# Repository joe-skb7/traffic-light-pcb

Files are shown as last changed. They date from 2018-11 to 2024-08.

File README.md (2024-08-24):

# "Traffic Light" system: hardware design files

Hardware files for traffic light model and interfacing board.

Corresponding software for controlling the interface board can be found at [1].

## Photo

Interfacing board, top view:

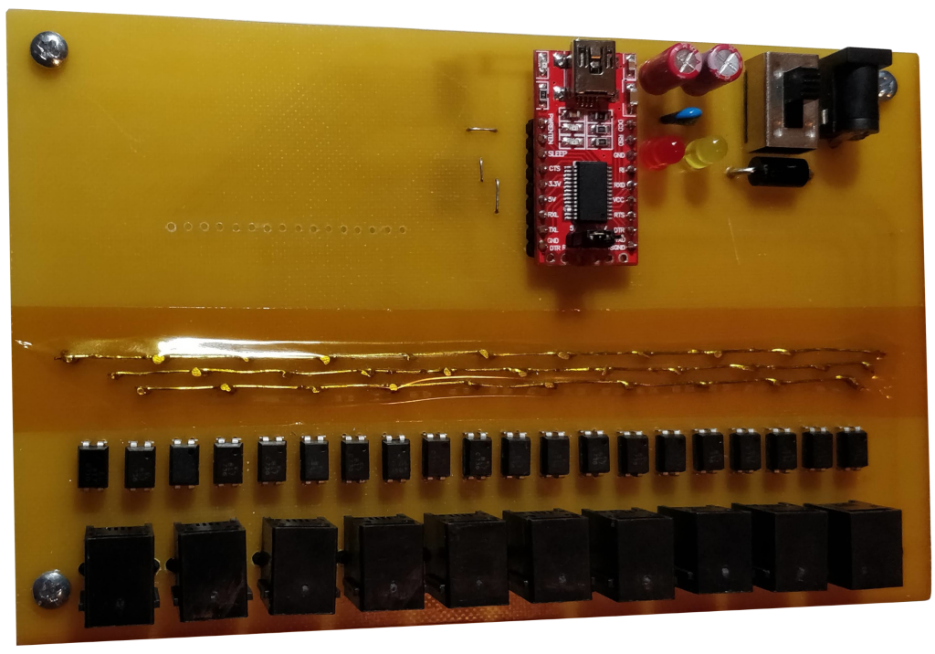
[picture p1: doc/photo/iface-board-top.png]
Interfacing Board, Top View


Interfacing board, bottom view:

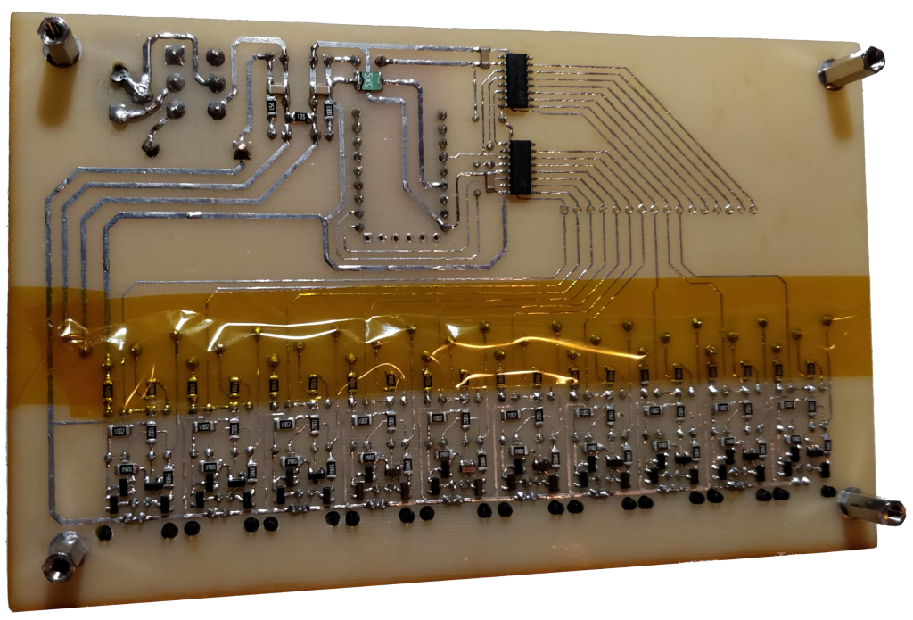
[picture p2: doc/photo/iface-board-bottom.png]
Interfacing Board, Bottom View


Traffic light board:

Traffic Light Board

## Overview

This repository consists of two KiCad projects:

1. Traffic light board (`light/*`):
   - it has 5 red and 5 green LEDs on it
2. Interfacing board (`iface/*`):
   - connect it to your PC (via USB cable) from one side
   - connect it to up to 10 traffic light boards (via phone cable) from other
     side

Kicad v5.0.1 was used.

You can find exported schematics in PDF format in `doc/output/` directory.

Once connected, use libtrl [1] to control traffic light boards via interface
board.

## Authors

**Sam Protsenko**

## License

This project is licensed under the GPLv3.

## References

[1] https://github.com/joe-skb7/libtrl

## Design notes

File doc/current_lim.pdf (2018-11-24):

### Simple Current Limit Circuit:

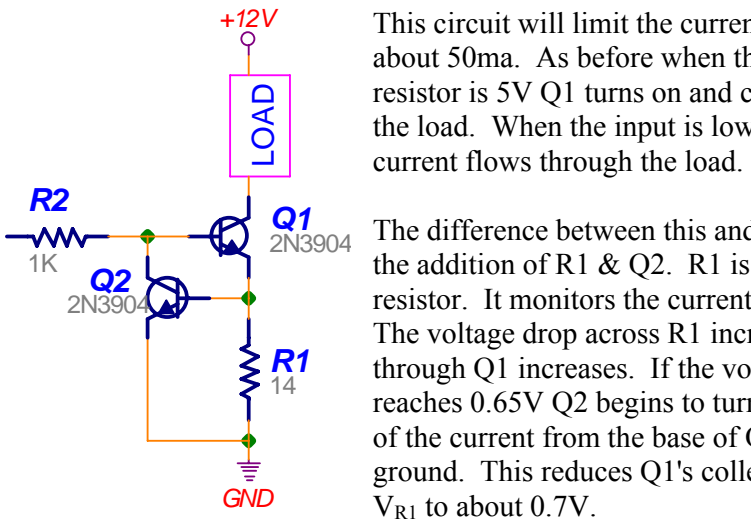
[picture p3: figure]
current flows through the load.; GND; 14LOAD; R1 to about 0.7V.

This circuit will limit the current through the load to about 50ma. As before when the input to the base resistor is 5V Q1 turns on and current flows through the load. When the input is low Q1 is off and no

GND

5V
The difference between this and the previous circuit is the addition of R1 & Q2. R1 is used as a current s resistor. It monitors the current flowing through Q1. The voltage drop across R1 increases as the curren through Q1 increases. If the voltage at the top of R1 reaches 0.65V Q2 begins to turn on. Q2 diverts some of the current from the base of Q1 and sends it to ground. This reduces Q1's collector current kee

ense

t

ping

The above circuit will act like a normal switch as long as the load doesn't try and draw too much current. If the load tries to draw too much current (50mA in this case) Q2 will divert some of the current away from Q1 and Q1 will increase the collector emitter voltage drop until the current is stable at about 50mA.

Calculations:

Let's say that Q2 turns on at 0.7V (it varies a little but this is close enough). We want to limit the current through the load to 50mA. The voltage drop across R1 should be 0.7V@50mA.
R1 = V/I = 0.7V/0.05A = 14Ω. Q1's base resistor is calculated the same as before but now you have to add in the extra 0.7V drop across the resistor. Since the worst case gain is 30 the base current should be: Ib = IC/30 = 50mA/30 = 1.7mA. We'll use 3mA so we have a safety margin.
R2 = (V – Vbe – VR1)/Ib = (5V – 0.7V – 0.7V)/3mA = 1.2KΩ. We'll use a 1KΩ (close enough).

Power dissipation:

Make sure you're transistor can dissipate the needed power in the worst case situation. If I short out the load with a wire (0Ω) almost the entire supply voltage (11.3V) will be dropped across the collector emitter junction of Q1 at 50mA. P = VI = 11.3V * 0.05A = 0.565W (quite a bit for the 2N3904).

Note: One reason to have a current limit is to protect the power supply incase the output gets shorted to ground. Without a current limit circuit a shorted power supply would most likely blow of fuse or melt a winding on the transformer (killing the supply). Always adjust the current limit on the bench power supply to only provide slightly more current than you think you need. This should keep you from destroying IC's & transistors when wired incorrectly.

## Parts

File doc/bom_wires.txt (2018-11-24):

1. Cable: Phone cable (4 wires, flat, copper, multicore/flexible).
   Qty: 100 meters (10 traffic lights, 10 meters per 1 traffic light).
   Possible option: [1].

2. Plugs: RJ9 (4P4C), for cable.
   Qty: 20 pcs (we need 10pcs, but let's buy 10 extra just in case).
   Possible option: [2].

3. Jacks: RJ9 (4P4C), for mounting on PCB, angled.
   Qty: 10 pcs.
   Possible option: [3].

4. Crimping tool for RJ9 (4P4C).
   Possible option: Hanlong HT-2094C [4].

References
----------

[1] https://e-server.com.ua/kabel-vitaya-para/telefonnyj-kabel/telefonnyj-kabel-4-zhily-ploskij-mednyj-chernyj-detail

[2] https://www.rcscomponents.kiev.ua/product/rj9-vilka-4p4c-kls12-rj11-4p4c-01_72297.html

[3] https://www.rcscomponents.kiev.ua/product/gnezdo-4p4c-kls12-123-4p4s-w-1-01-2-kls_72300.html

[4] https://e-server.com.ua/instrumenty-i-testery/instrumenty/instrument-dlya-obzhimaniya-konnektorov-rj-11-4p4c-4p2c-hanlong-detail

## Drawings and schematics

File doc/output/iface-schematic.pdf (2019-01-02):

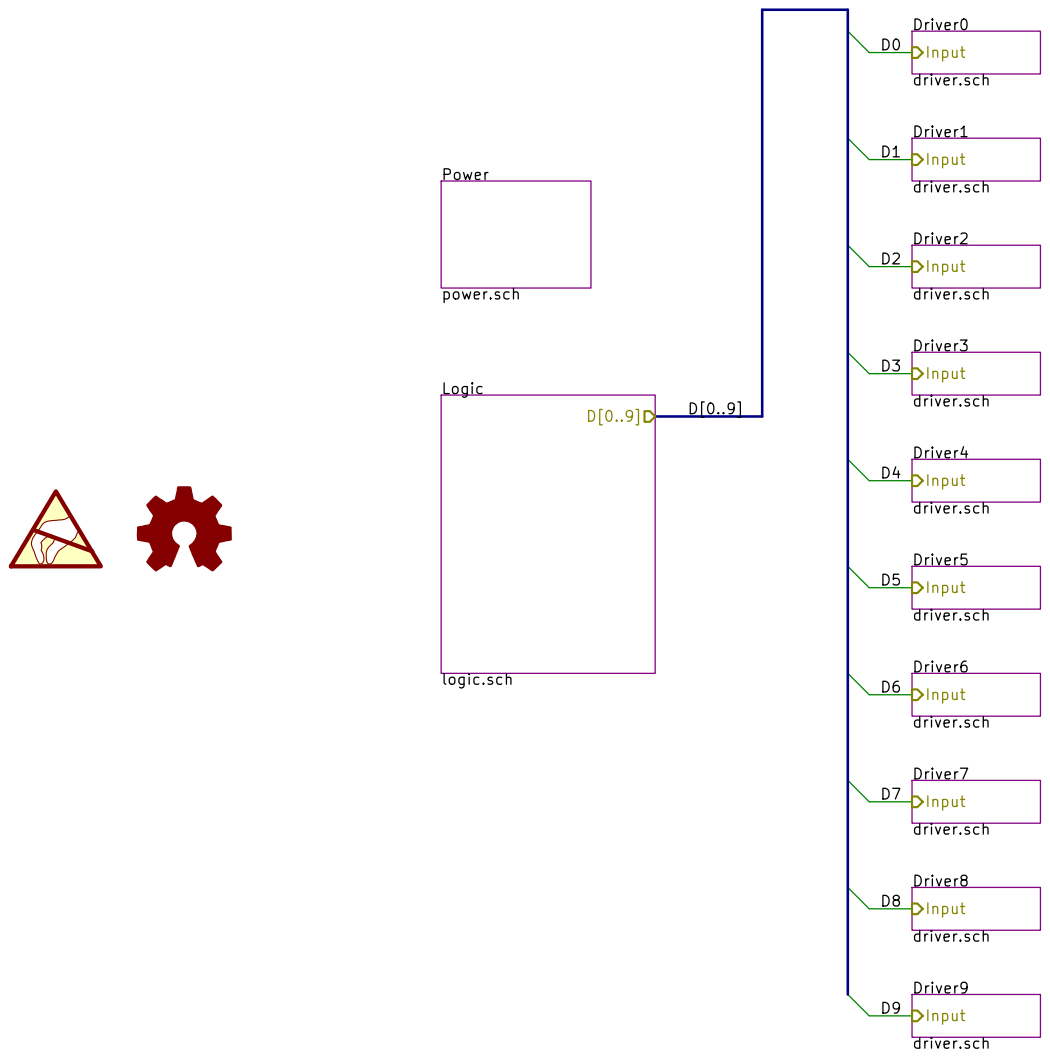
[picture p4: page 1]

Author: Sam Protsenko <semen.protsenko@globallogic.com>
File: iface.sch Sheet: / GlobalLogic

Id: 1/13 Title: Traffic Light Interface Board

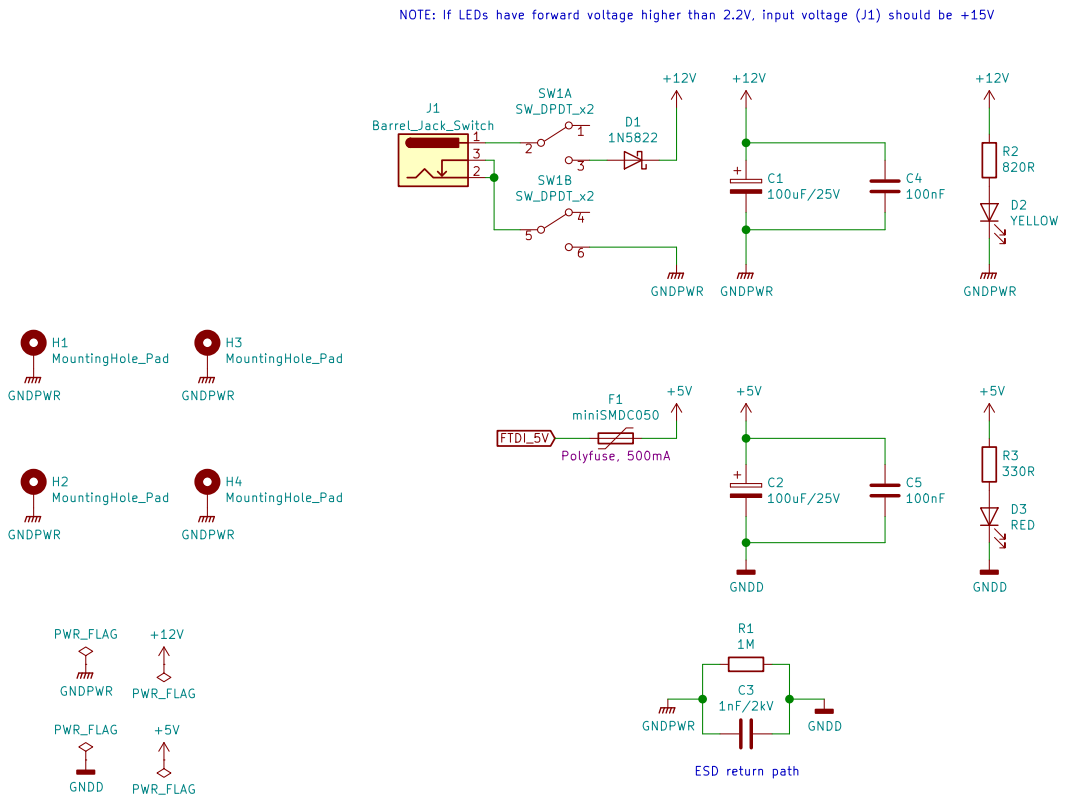
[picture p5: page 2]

SW_DPDT_x2 NOTE: If LEDs have forward voltage higher than 2.2V, input voltage (J1) should be +15V

Author: Sam Protsenko <semen.protsenko@globallogic.com>
File: power.sch Sheet: /Power/ GlobalLogic

Id: 2/13 Title: Power scheme

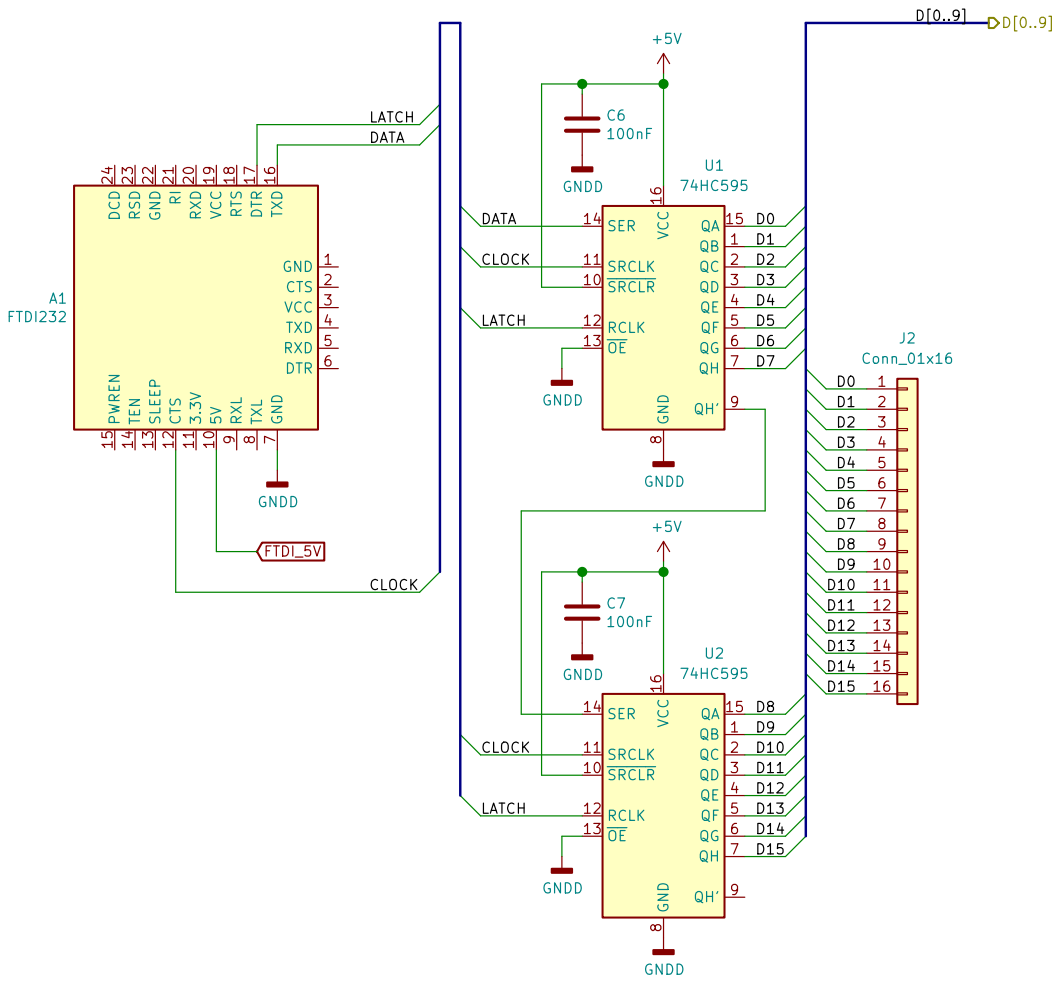
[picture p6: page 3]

Author: Sam Protsenko <semen.protsenko@globallogic.com>
GlobalLogic
Sheet: /Logic/
File: logic.sch
Id: 3/13 Title: Logic scheme

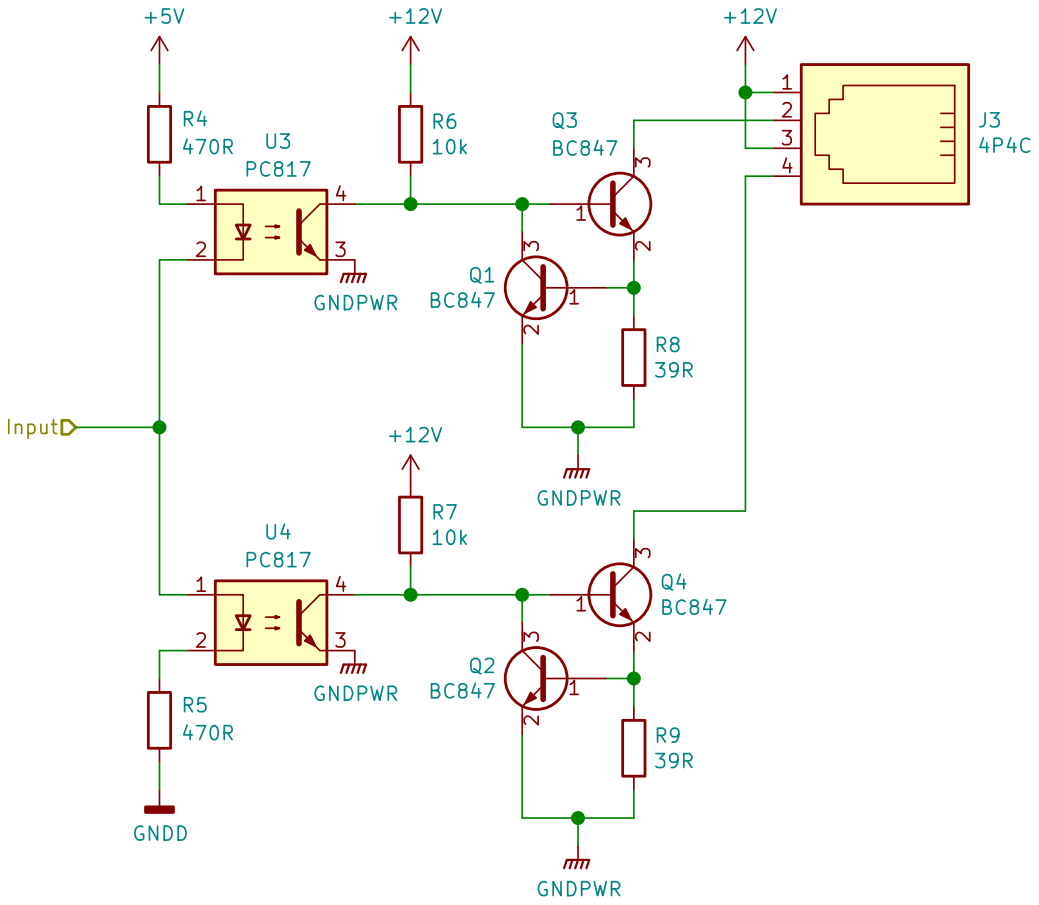
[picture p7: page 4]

Author: Sam Protsenko <semen.protsenko@globallogic.com>
Id: 4/13 Title: LED Driver File: driver.sch Sheet: /Driver0/ GlobalLogic

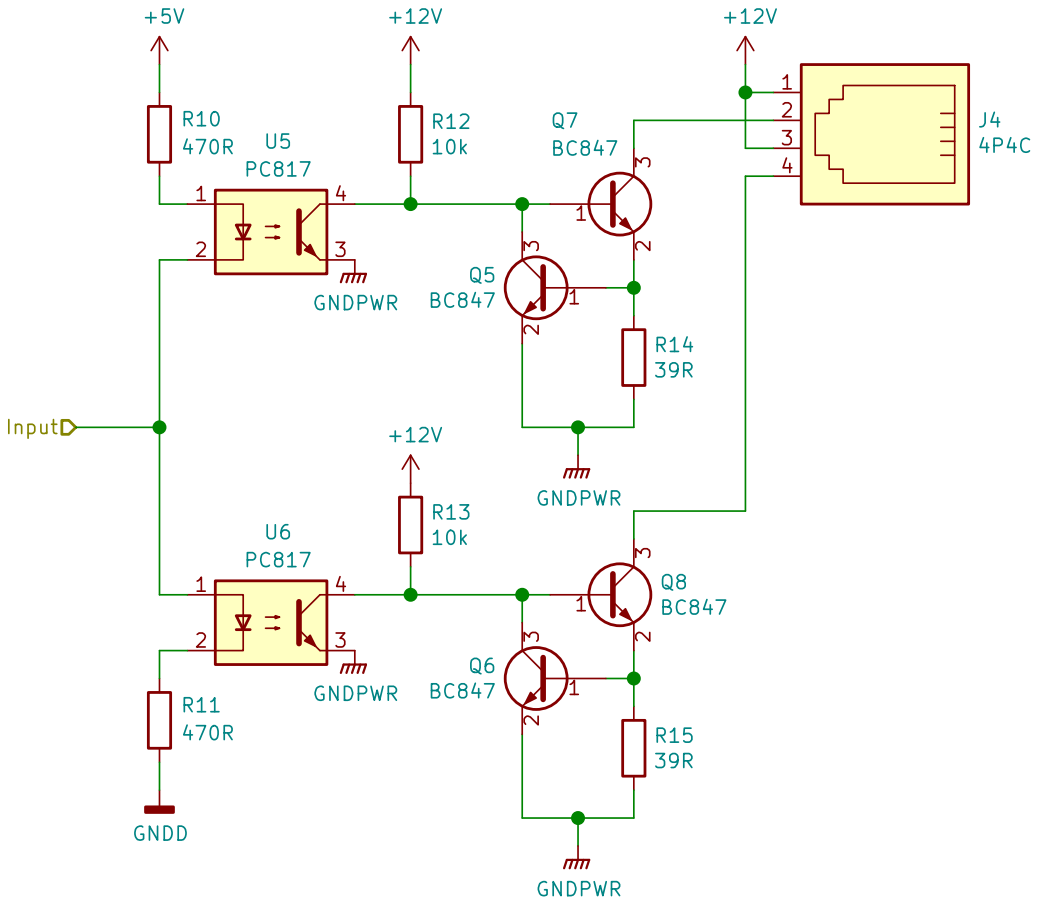
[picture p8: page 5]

Author: Sam Protsenko <semen.protsenko@globallogic.com>
Id: 5/13 Title: LED Driver File: driver.sch Sheet: /Driver1/ GlobalLogic

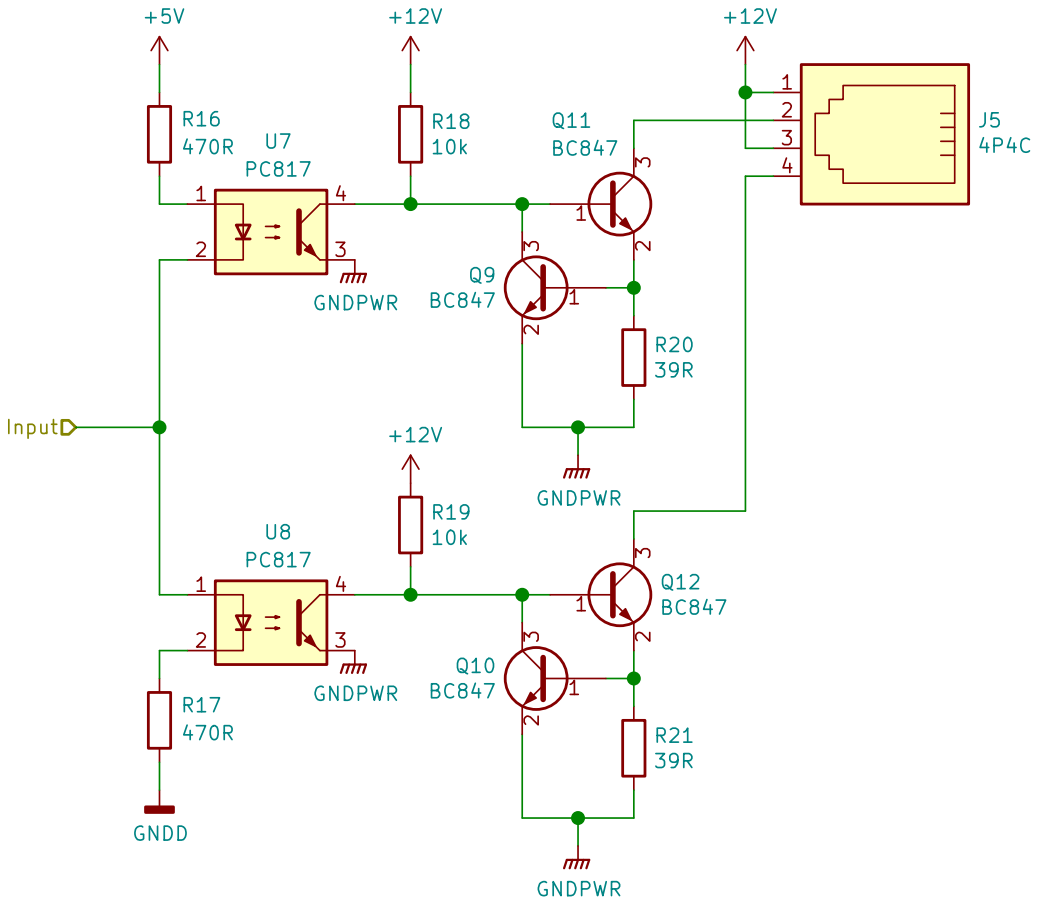
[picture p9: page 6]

Author: Sam Protsenko <semen.protsenko@globallogic.com>
Id: 6/13 Title: LED Driver File: driver.sch Sheet: /Driver2/ GlobalLogic

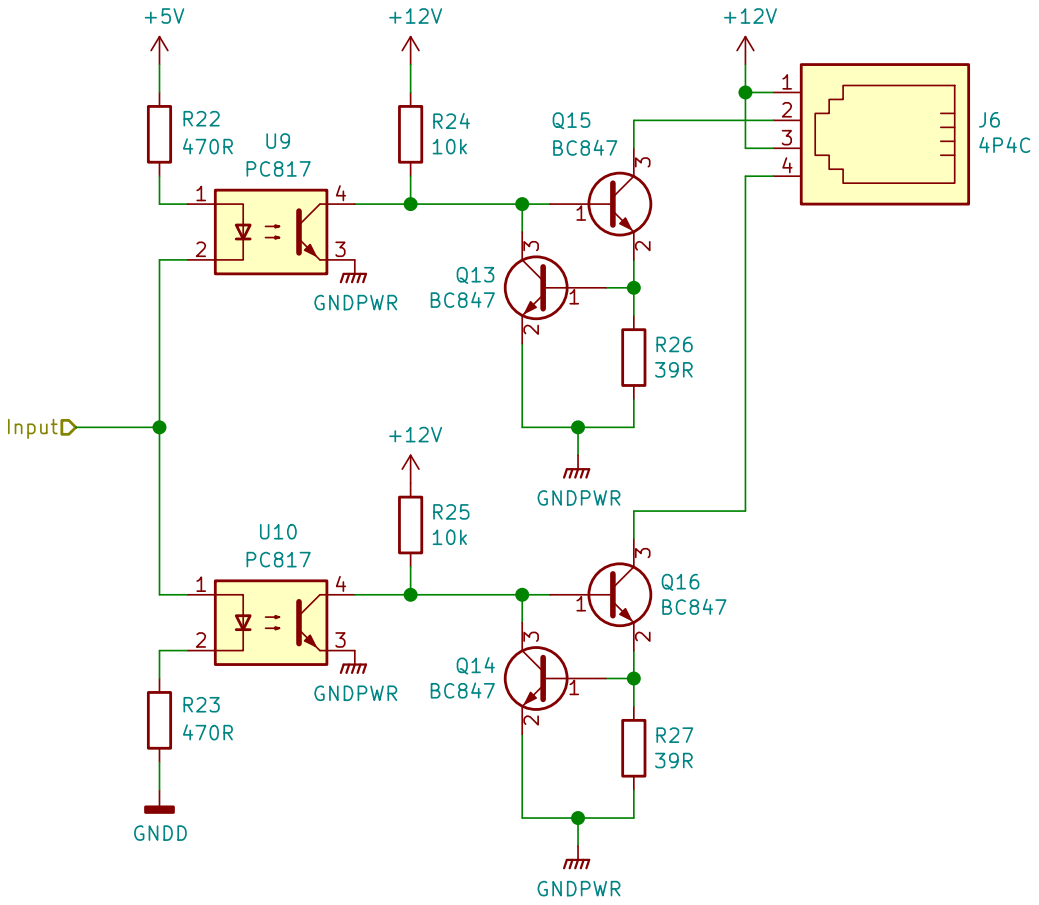
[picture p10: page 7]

Author: Sam Protsenko <semen.protsenko@globallogic.com>
Id: 7/13 Title: LED Driver File: driver.sch Sheet: /Driver3/ GlobalLogic

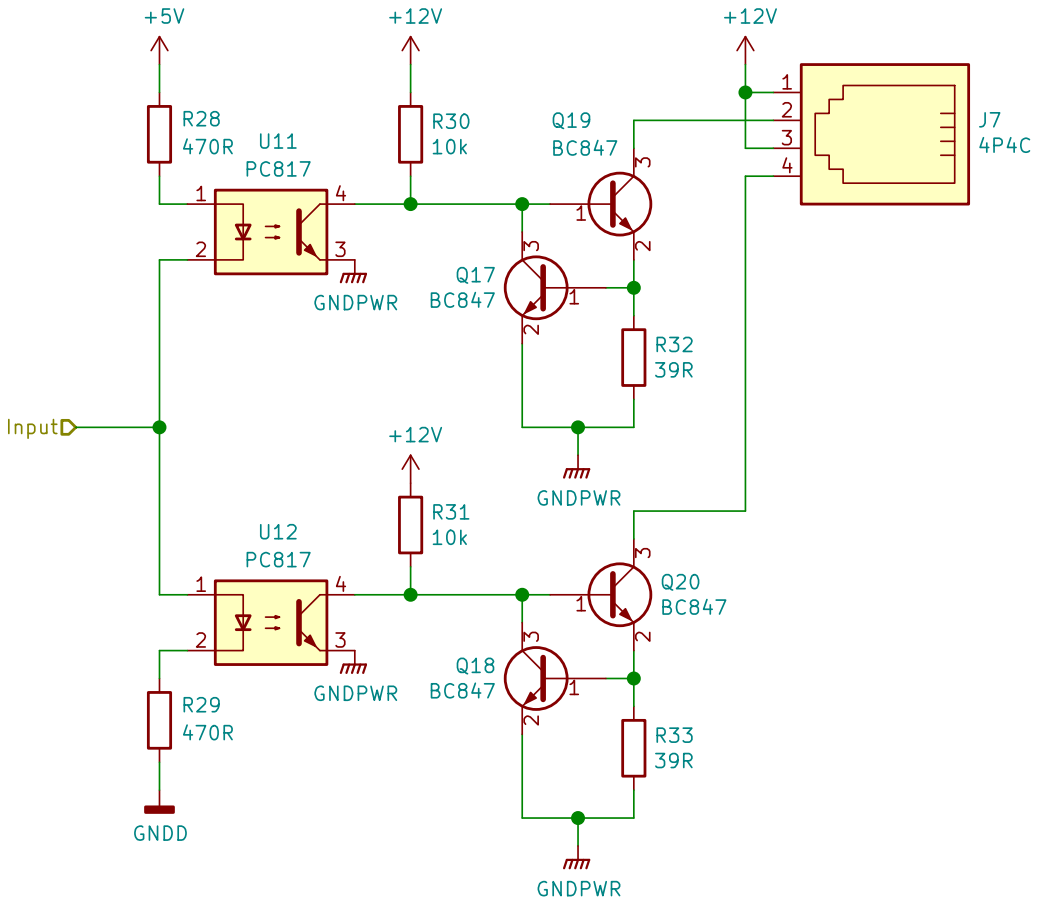
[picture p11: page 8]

Author: Sam Protsenko <semen.protsenko@globallogic.com>
Id: 8/13 Title: LED Driver File: driver.sch Sheet: /Driver4/ GlobalLogic

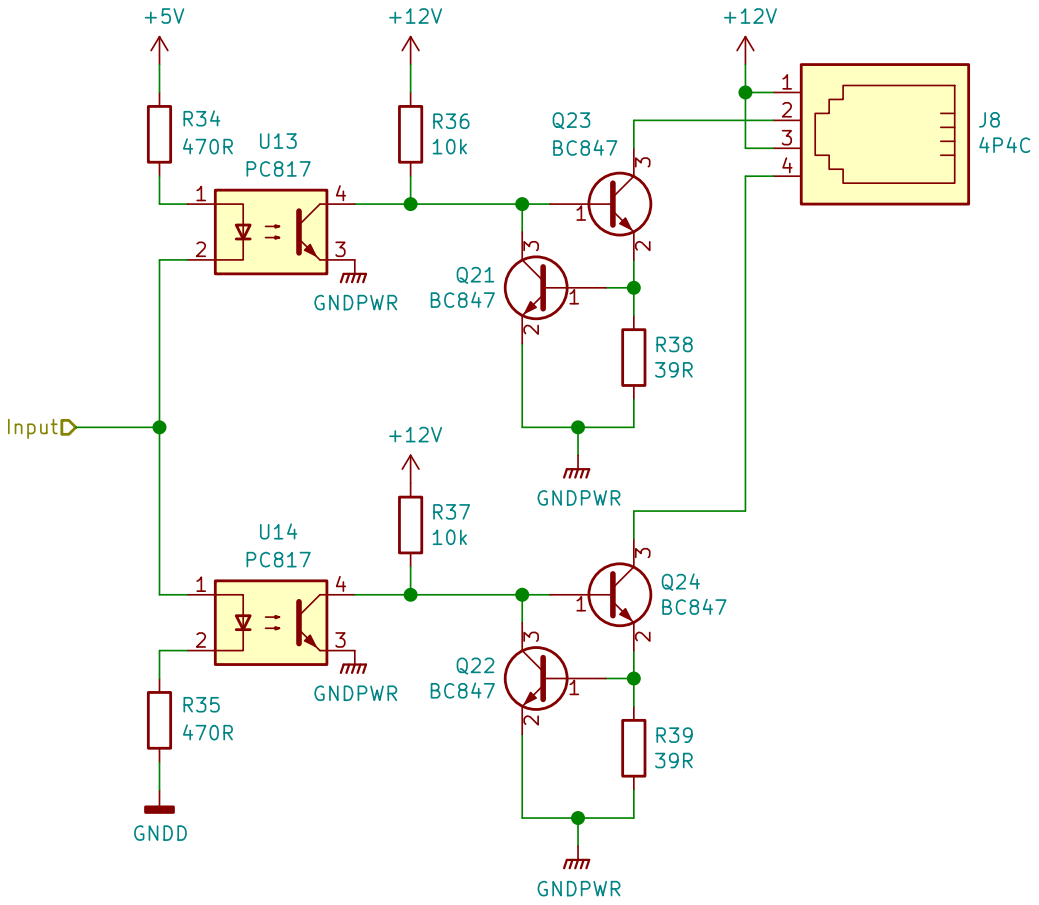
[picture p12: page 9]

Author: Sam Protsenko <semen.protsenko@globallogic.com>
Id: 9/13 Title: LED Driver File: driver.sch Sheet: /Driver5/ GlobalLogic

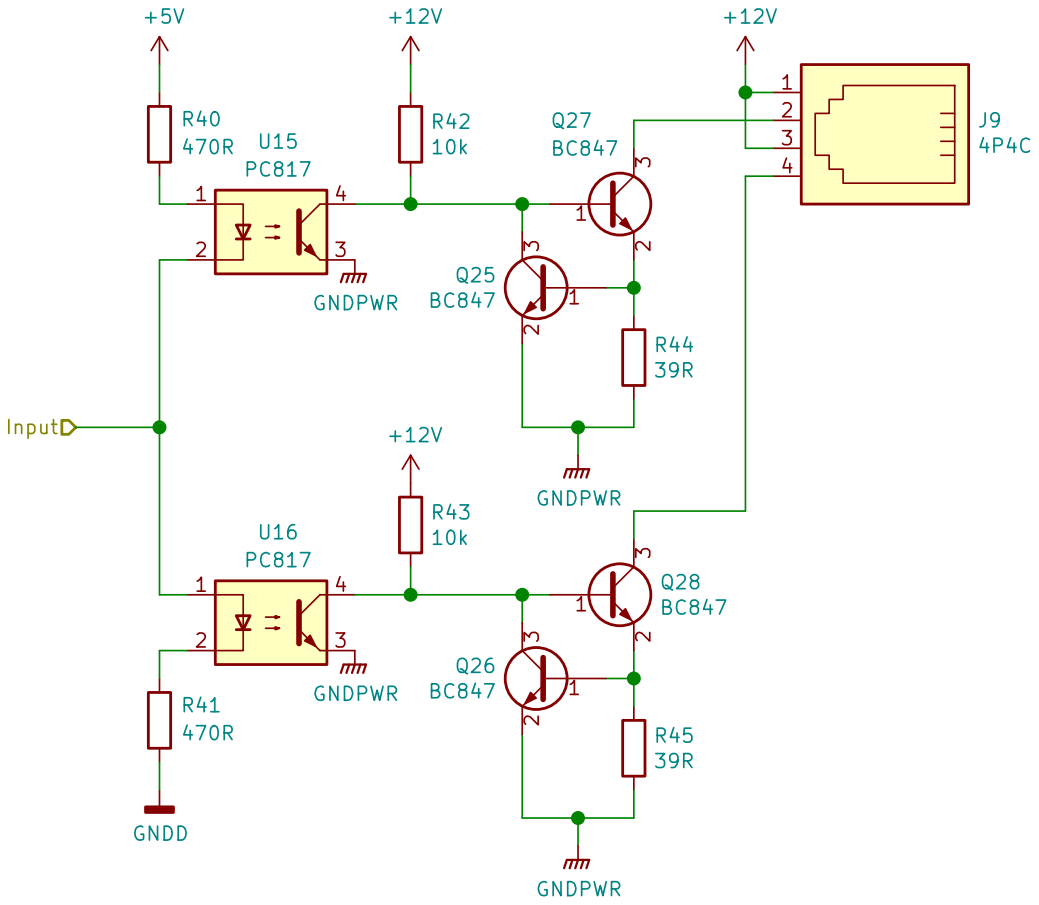
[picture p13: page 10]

Author: Sam Protsenko <semen.protsenko@globallogic.com>
Id: 10/13 Title: LED Driver File: driver.sch Sheet: /Driver6/ GlobalLogic

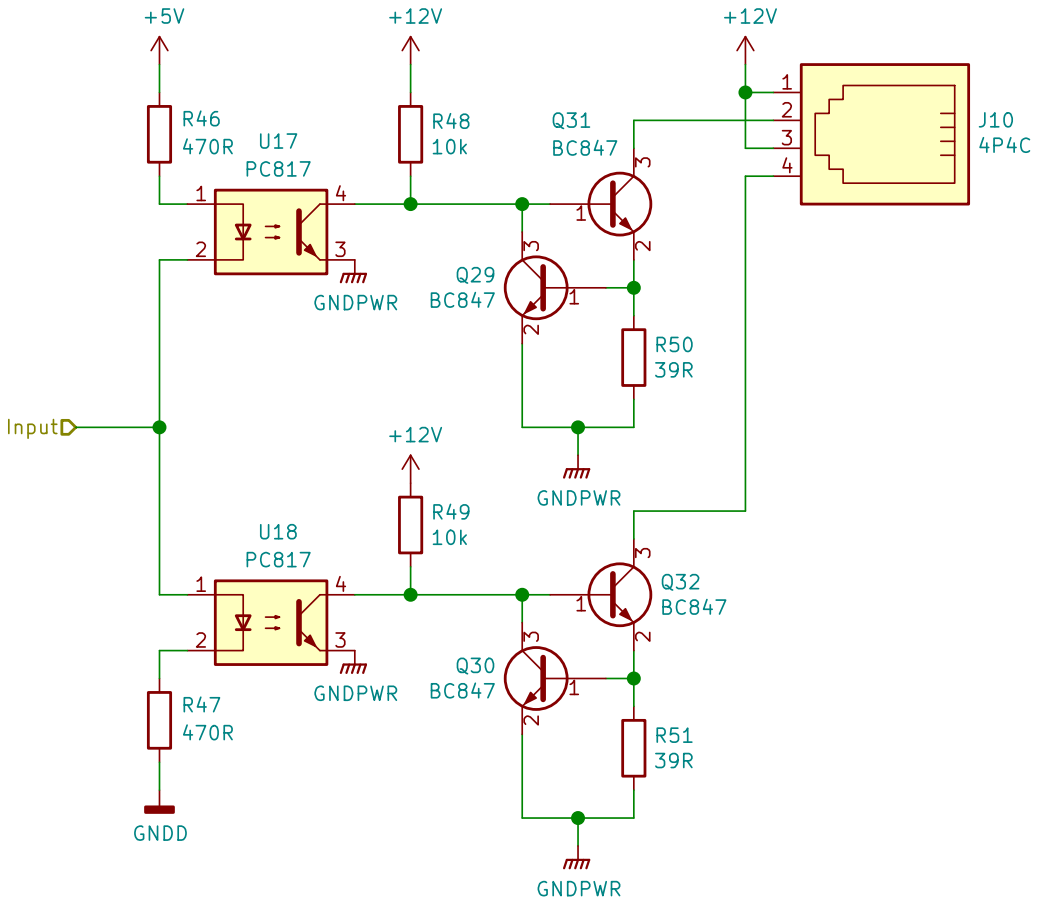
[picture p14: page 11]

Author: Sam Protsenko <semen.protsenko@globallogic.com>
Id: 11/13 Title: LED Driver File: driver.sch Sheet: /Driver7/ GlobalLogic

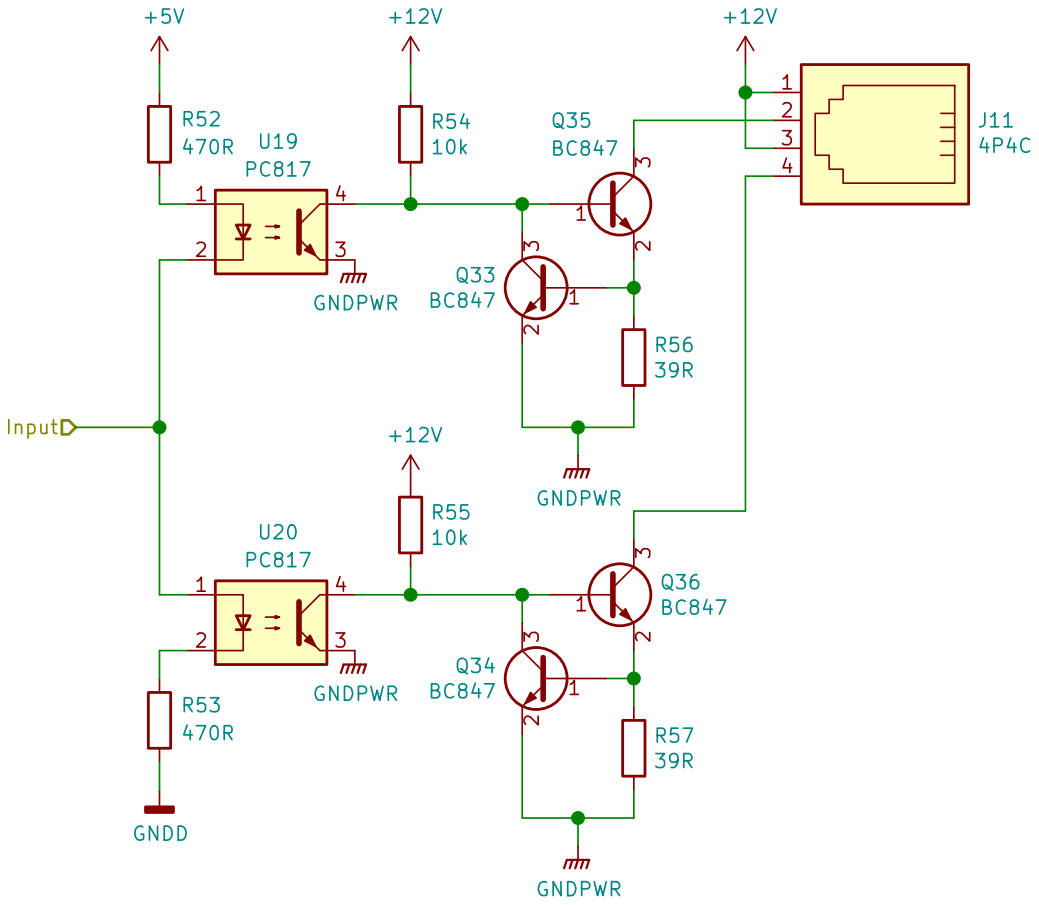
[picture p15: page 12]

Author: Sam Protsenko <semen.protsenko@globallogic.com>
Id: 12/13 Title: LED Driver File: driver.sch Sheet: /Driver8/ GlobalLogic


Author: Sam Protsenko <semen.protsenko@globallogic.com>
Id: 13/13 Title: LED Driver File: driver.sch Sheet: /Driver9/ GlobalLogic

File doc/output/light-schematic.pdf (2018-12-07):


Author: Sam Protsenko <semen.protsenko@globallogic.com>
File: light.sch Sheet: / GlobalLogic

Id: 1/1 Title: Traffic Light

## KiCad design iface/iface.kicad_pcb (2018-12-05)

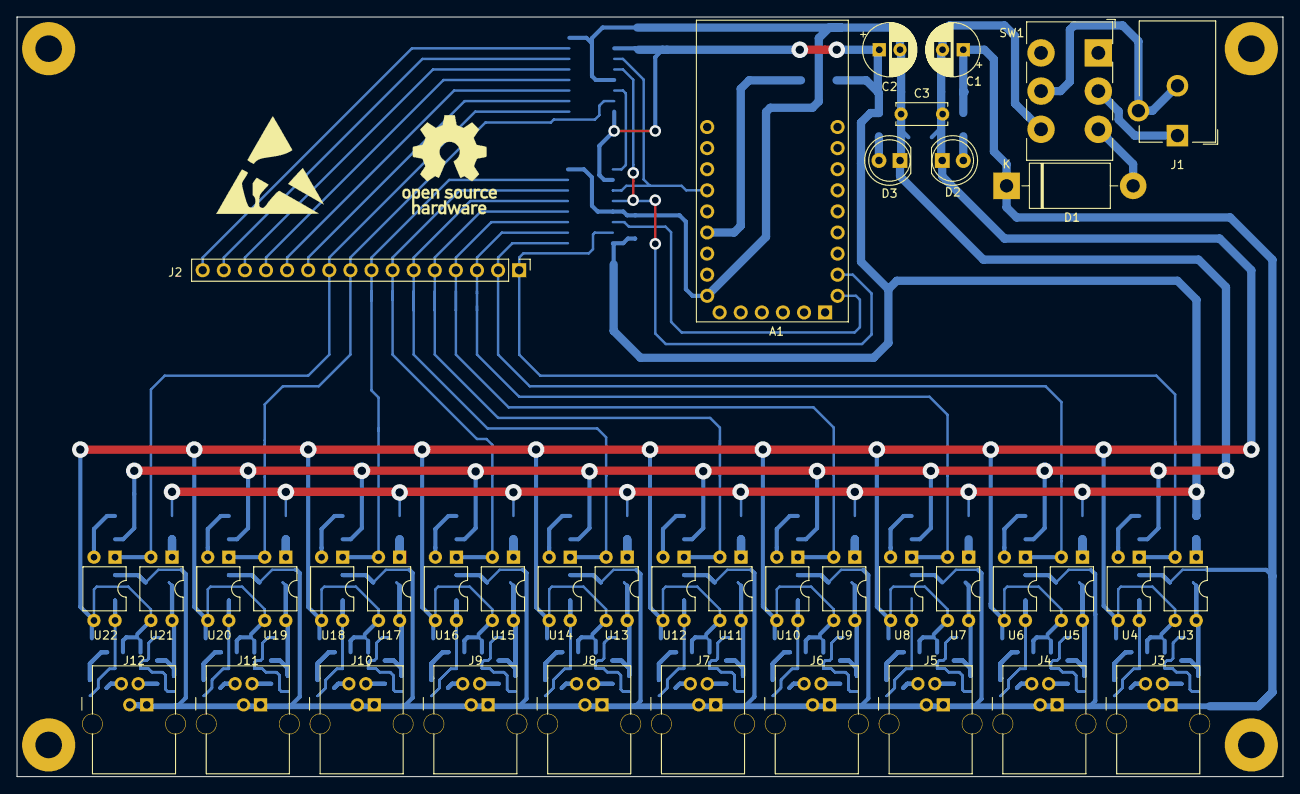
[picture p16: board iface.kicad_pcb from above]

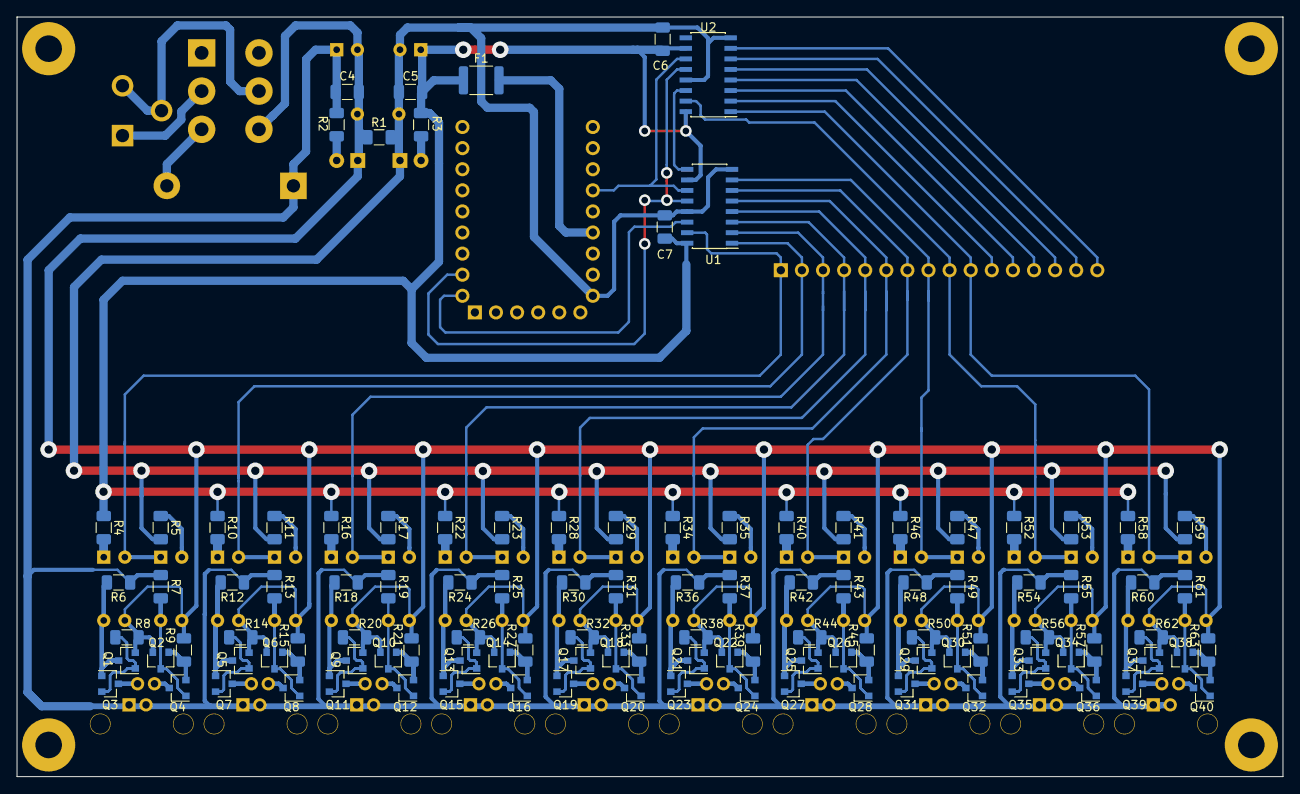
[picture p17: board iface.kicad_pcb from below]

Board: 2 copper layers, 152.4 x 91.4 mm, 156 parts (110 on the bottom side), 110 nets.

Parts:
A1: FTDI232
C1, C2: 100uF/25V; CP_Radial_D6.3mm_P2.50mm
C3: 1nF/2kV; C_Disc_D6.0mm_W2.5mm_P5.00mm
C4, C5, C6, C7: 100nF; C_1206_3216Metric
D1: 1N5822; D_DO-201AD_P15.24mm_Horizontal
D2: YELLOW; LED_D5.0mm
D3: RED; LED_D5.0mm
F1: Polyfuse; Fuse_1812_4532Metric
H1, H2, H3, H4: MountingHole_Pad; MountingHole_3.2mm_M3_Pad
J1: Barrel_Jack_Switch; BarrelJack_CUI_PJ-102AH_Horizontal
J2: Conn_01x16; PinHeader_1x16_P2.54mm_Vertical
J3, J4, J5, J6, J7, J8, J9, J10, J11, J12: 4P4C; RJ9_KLS_12-123-4P
Q1, Q2, Q3, Q4, Q5, Q6, Q7, Q8, Q9, Q10, Q11, Q12, Q13, Q14, Q15, Q16, Q17, Q18, Q19, Q20, Q21, Q22, Q23, Q24, Q25, Q26, Q27, Q28, Q29, Q30, Q31, Q32, Q33, Q34, Q35, Q36, Q37, Q38, Q39, Q40: BC847; SOT-23
R1: 1M; R_1206_3216Metric
R2: 820R; R_1206_3216Metric
R3: 330R; R_1206_3216Metric
R4, R5, R10, R11, R16, R17, R22, R23, R28, R29, R34, R35, R40, R41, R46, R47, R52, R53, R58, R59: 470R; R_1206_3216Metric
R6, R7, R12, R13, R18, R19, R24, R25, R30, R31, R36, R37, R42, R43, R48, R49, R54, R55, R60, R61: 10k; R_1206_3216Metric
R8, R9, R14, R15, R20, R21, R26, R27, R32, R33, R38, R39, R44, R45, R50, R51, R56, R57, R62, R63: 39R; R_1206_3216Metric
SW1: SW_DPDT_x2; SW_CW_GF-126-0305_DPDT
SYM1: SYM_ESD_Large; ESD-Logo_13.2x12mm_SilkScreen
SYM2: Logo_Open_Hardware_Small; OSHW-Logo_11.4x12mm_SilkScreen
U1, U2: 74HC595; SOIC-16_3.9x9.9mm_P1.27mm
U3, U4, U5, U6, U7, U8, U9, U10, U11, U12, U13, U14, U15, U16, U17, U18, U19, U20, U21, U22: PC817; DIP-4_W7.62mm

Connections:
+5V: C2.1, C5.1, C6.1, C7.1, F1.1, R3.2, R4.2, R10.2, R16.2, R22.2, R28.2, R34.2, R40.2, R46.2, R52.2, R58.2, U1.10, U1.16, U2.10, U2.16
+12V: C1.1, C4.1, D1.1, J3.1, J3.3, J4.1, J4.3, J5.1, J5.3, J6.1, J6.3, J7.1, J7.3, J8.1, J8.3, J9.1, J9.3, J10.1, J10.3, J11.1, J11.3, J12.1, J12.3, R2.2, R6.1, R7.1, R12.1, R13.1, R18.1, R19.1, R24.1, R25.1, R30.1, R31.1, R36.1, R37.1, R42.1, R43.1, R48.1, R49.1, R54.1, R55.1, R60.1, R61.1
/D0: J2.1, U1.15, U3.2, U4.1
/D1: J2.2, U1.1, U5.2, U6.1
/D2: J2.3, U1.2, U7.2, U8.1
/D3: J2.4, U1.3, U9.2, U10.1
/D4: J2.5, U1.4, U11.2, U12.1
/D5: J2.6, U1.5, U13.2, U14.1
/D6: J2.7, U1.6, U15.2, U16.1
/D7: J2.8, U1.7, U17.2, U18.1
/D8: J2.9, U2.15, U19.2, U20.1
/D9: J2.10, U2.1, U21.2, U22.1
/Logic/CLOCK: A1.12, U1.11, U2.11
/Logic/D10: J2.11, U2.2
/Logic/D11: J2.12, U2.3
/Logic/D12: J2.13, U2.4
/Logic/D13: J2.14, U2.5
/Logic/D14: J2.15, U2.6
/Logic/D15: J2.16, U2.7
/Logic/DATA: A1.16, U1.14
/Logic/LATCH: A1.17, U1.12, U2.12
FTDI_5V: A1.10, F1.2
GNDD: A1.7, C2.2, C3.1, C5.2, C6.2, C7.2, D3.1, R1.1, R5.1, R11.1, R17.1, R23.1, R29.1, R35.1, R41.1, R47.1, R53.1, R59.1, U1.8, U1.13, U2.8, U2.13
GNDPWR: C1.2, C3.2, C4.2, D2.1, H1.1, H2.1, H3.1, H4.1, Q1.2, Q2.2, Q5.2, Q6.2, Q9.2, Q10.2, Q13.2, Q14.2, Q17.2, Q18.2, Q21.2, Q22.2, Q25.2, Q26.2, Q29.2, Q30.2, Q33.2, Q34.2, Q37.2, Q38.2, R1.2, R8.2, R9.2, R14.2, R15.2, R20.2, R21.2, R26.2, R27.2, R32.2, R33.2, R38.2, R39.2, R44.2, R45.2, R50.2, R51.2, R56.2, R57.2, R62.2, R63.2, SW1.6, U3.3, U4.3, U5.3, U6.3, U7.3, U8.3, U9.3, U10.3, U11.3, U12.3, U13.3, U14.3, U15.3, U16.3, U17.3, U18.3, U19.3, U20.3, U21.3, U22.3
unnamed: D1.2, SW1.3
unnamed: D2.2, R2.1
unnamed: D3.2, R3.1
unnamed: J1.1, SW1.2
unnamed: J1.2, J1.3, SW1.5
unnamed: J3.2, Q3.3
unnamed: J3.4, Q4.3
unnamed: J4.2, Q7.3
unnamed: J4.4, Q8.3
unnamed: J5.2, Q11.3
unnamed: J5.4, Q12.3
unnamed: J6.2, Q15.3
unnamed: J6.4, Q16.3
unnamed: J7.2, Q19.3
unnamed: J7.4, Q20.3
unnamed: J8.2, Q23.3
unnamed: J8.4, Q24.3
unnamed: J9.2, Q27.3
unnamed: J9.4, Q28.3
unnamed: J10.2, Q31.3
unnamed: J10.4, Q32.3
unnamed: J11.2, Q35.3
unnamed: J11.4, Q36.3
unnamed: J12.2, Q39.3
unnamed: J12.4, Q40.3
unnamed: Q1.1, Q3.2, R8.1
unnamed: Q1.3, Q3.1, R6.2, U3.4
unnamed: Q2.1, Q4.2, R9.1
unnamed: Q2.3, Q4.1, R7.2, U4.4
unnamed: Q5.1, Q7.2, R14.1
unnamed: Q5.3, Q7.1, R12.2, U5.4
unnamed: Q6.1, Q8.2, R15.1
unnamed: Q6.3, Q8.1, R13.2, U6.4
unnamed: Q10.1, Q12.2, R21.1
unnamed: Q10.3, Q12.1, R19.2, U8.4
unnamed: Q9.3, Q11.1, R18.2, U7.4
unnamed: Q9.1, Q11.2, R20.1
unnamed: Q13.1, Q15.2, R26.1
unnamed: Q13.3, Q15.1, R24.2, U9.4
unnamed: Q14.1, Q16.2, R27.1
unnamed: Q14.3, Q16.1, R25.2, U10.4
unnamed: Q17.1, Q19.2, R32.1
unnamed: Q17.3, Q19.1, R30.2, U11.4
unnamed: Q18.1, Q20.2, R33.1
unnamed: Q18.3, Q20.1, R31.2, U12.4
unnamed: Q21.1, Q23.2, R38.1
unnamed: Q21.3, Q23.1, R36.2, U13.4
unnamed: Q22.1, Q24.2, R39.1
unnamed: Q22.3, Q24.1, R37.2, U14.4
unnamed: Q25.1, Q27.2, R44.1
unnamed: Q25.3, Q27.1, R42.2, U15.4
unnamed: Q26.1, Q28.2, R45.1
unnamed: Q26.3, Q28.1, R43.2, U16.4
unnamed: Q29.1, Q31.2, R50.1
unnamed: Q29.3, Q31.1, R48.2, U17.4
unnamed: Q30.1, Q32.2, R51.1
unnamed: Q30.3, Q32.1, R49.2, U18.4
unnamed: Q33.1, Q35.2, R56.1
unnamed: Q33.3, Q35.1, R54.2, U19.4
unnamed: Q34.1, Q36.2, R57.1
unnamed: Q34.3, Q36.1, R55.2, U20.4
unnamed: Q37.1, Q39.2, R62.1
unnamed: Q37.3, Q39.1, R60.2, U21.4
unnamed: Q38.1, Q40.2, R63.1
unnamed: Q38.3, Q40.1, R61.2, U22.4
unnamed: R4.1, U3.1
unnamed: R5.2, U4.2
unnamed: R10.1, U5.1
unnamed: R11.2, U6.2
unnamed: R16.1, U7.1
unnamed: R17.2, U8.2
unnamed: R22.1, U9.1
unnamed: R23.2, U10.2
unnamed: R28.1, U11.1
unnamed: R29.2, U12.2
unnamed: R34.1, U13.1
unnamed: R35.2, U14.2
unnamed: R40.1, U15.1
unnamed: R41.2, U16.2
unnamed: R46.1, U17.1
unnamed: R47.2, U18.2
unnamed: R52.1, U19.1
unnamed: R53.2, U20.2
unnamed: R58.1, U21.1
unnamed: R59.2, U22.2
unnamed: U1.9, U2.14

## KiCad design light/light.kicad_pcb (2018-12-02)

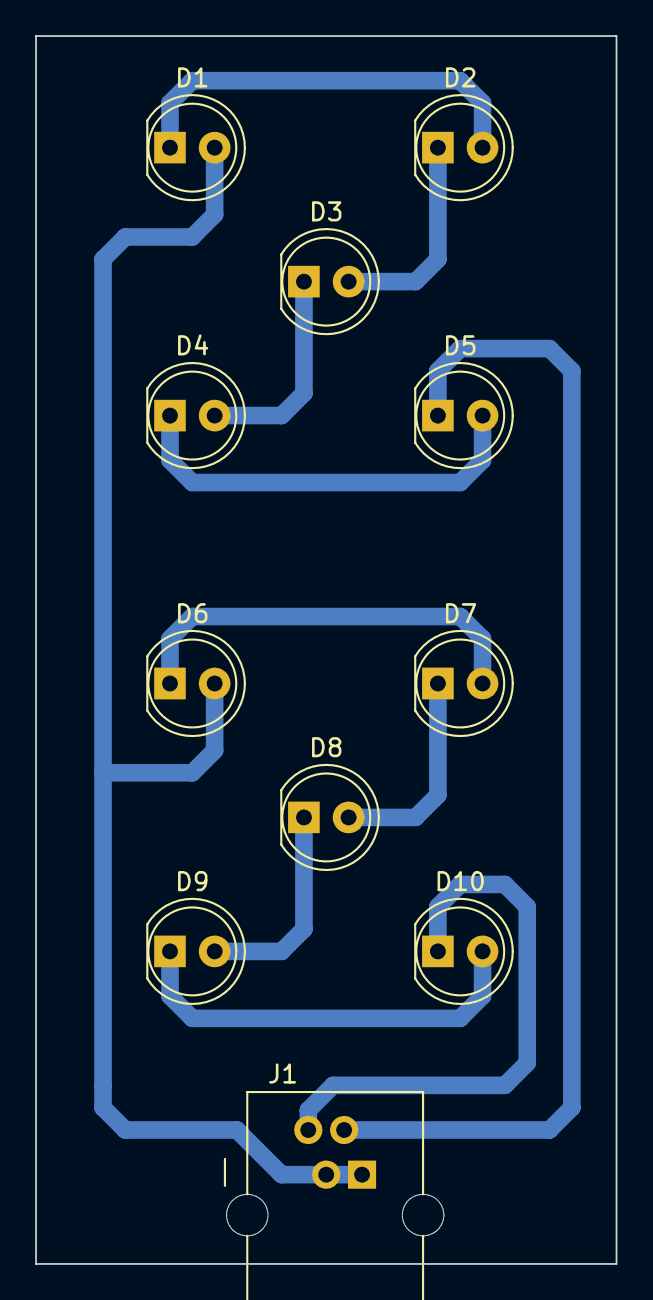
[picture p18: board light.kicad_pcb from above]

Board: 2 copper layers, 33.0 x 69.8 mm, 11 parts (0 on the bottom side), 11 nets.

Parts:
D1, D2, D3, D4, D5: Red; LED_D5.0mm
D6, D7, D8, D9, D10: Green; LED_D5.0mm
J1: 4P4C; RJ9_KLS_12-123-4P

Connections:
unnamed: D1.1, D2.2
unnamed: D1.2, D6.2, J1.1, J1.3
unnamed: D2.1, D3.2
unnamed: D3.1, D4.2
unnamed: D4.1, D5.2
unnamed: D5.1, J1.2
unnamed: D6.1, D7.2
unnamed: D7.1, D8.2
unnamed: D8.1, D9.2
unnamed: D10.1, J1.4
unnamed: D9.1, D10.2

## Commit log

2018-11-24 lib: Add footprint for 4P4C (RJ9) jack connector
    Will be used further for interface board.
2018-11-24 light: Add KiCad project for traffic light PCB
    [light.kicad_pcb, light.sch]
2018-11-24 iface: Add KiCad project for interface board
    Initial files. Work is still in progress.
    [iface.sch]
2018-11-27 light: Finish scheme and PCB
    [light.kicad_pcb, light.sch]
2018-11-27 doc: Add traffic light PCB in PDF for toner transfer method
2018-11-28 lib: Add symbol and footprint for FTDI232 module
2018-11-28 lib: Add symbol and footprint for MP1584 module
2018-11-28 light: Add info about local footprint
2018-11-28 iface: Add info about local footprints
2018-11-28 iface: Continue working on schematic
    [iface.sch]
2018-11-29 lib: mp1584: Fix power output pins
2018-11-29 iface: Finish schematic
    [driver.sch, iface.sch, logic.sch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]
2018-11-30 iface: schematic: Final edits
    [driver.sch, iface.sch, logic.sch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]
2018-12-01 lib: Add footprint for my DPDT switch
2018-12-01 iface: scheme: Add DPDT switch
    [driver.sch, iface.sch, logic.sch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]
2018-12-02 light: Use two pins of RJ9 to pass +12V
    [light.kicad_pcb, light.sch]
2018-12-02 iface: Re-wire FTDI232 lines and add some notes to power scheme
    [driver.sch, logic.sch, power.sch]
2018-12-02 iface: Start routing PCB layout
    [iface.kicad_pcb]
2018-12-03 iface: Use different kind of grounds
    [driver.sch, iface.sch, logic.sch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]
2018-12-04 iface: Simplify schematic
    Apply next changes in order to simplify schematics:
    - use wired logic on optocoupler inputs to get inverted signal;
    driver.sch files was modified; this way we can get rid of two
    inverters (74HC04)
    - use 5V line from USB; this way we can get rid from buck-boost DC-DC
    converter module (MP1584)
    - split power and signal grounds completely, providing proper ESD
    connection; this way our LED drivers are completely isolated from
    logic part, and can't damage neither chips, nor USB
    [driver.sch, iface.sch, logic.sch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]
2018-12-04 iface: Finish routing the PCB layout
    [driver.sch, iface.kicad_pcb, iface.sch]
2018-12-05 iface: Update PCB for toner transfer method
    [iface.kicad_pcb]
2018-12-05 iface: Add description for used Polyfuse
    [power.sch]
2018-12-05 iface: Fix notes on power scheme
    [power.sch]
2018-12-07 output: Add exported schematics
2018-12-08 Move PDF schematics to doc/
2019-01-02 iface: schematic: Fix resistor designators on driver sheets
    Fixes: #1
    [driver.sch]
2024-08-24 README: Mention KiCad version used to create schematics and PCB
